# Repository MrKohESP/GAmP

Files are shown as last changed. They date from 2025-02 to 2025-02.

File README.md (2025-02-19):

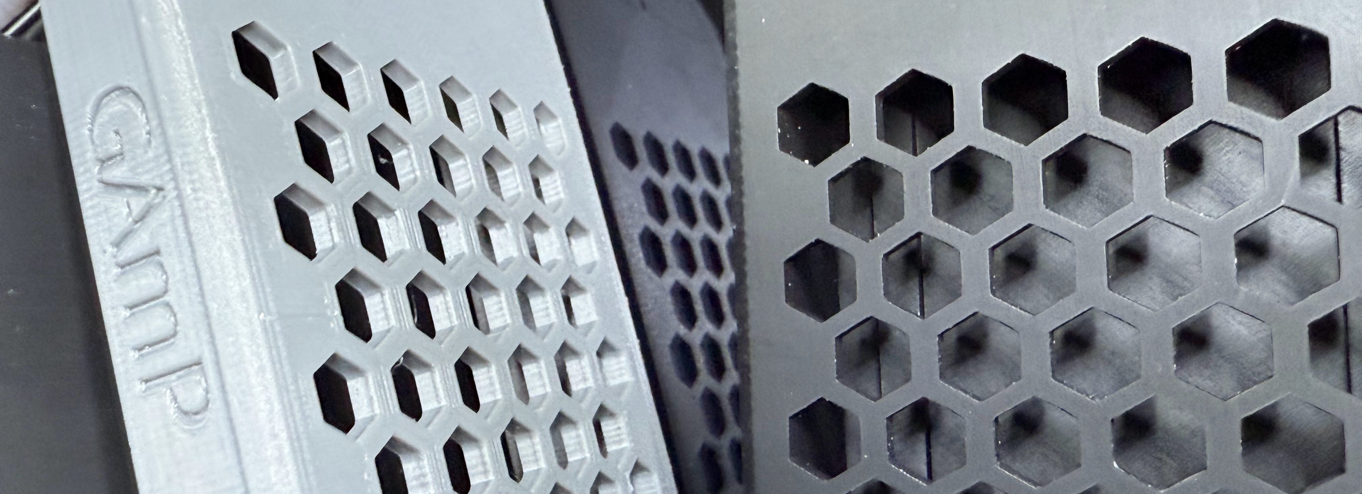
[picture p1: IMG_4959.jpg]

# GAmP
This circuit and subsequent project and headphone amplifier was designed and built for Mr. Koh's birthday.  It was built with web based tools only including [circuitlab.com](https:circuitlab.com), [EasyEDA](https://pro.easyeda.com/), and [onshape.com](https://onshape.com).

# Happy Birthday Mr. Koh 2025

This GAmP is a discret transister class A headphone amplifier capabable of driving headphones from 16 ohms to 600 ohms.  While only tested on 16 and 300 ohms the differences in performance for any impedences above 90 ohms were all similar.

# Schematic
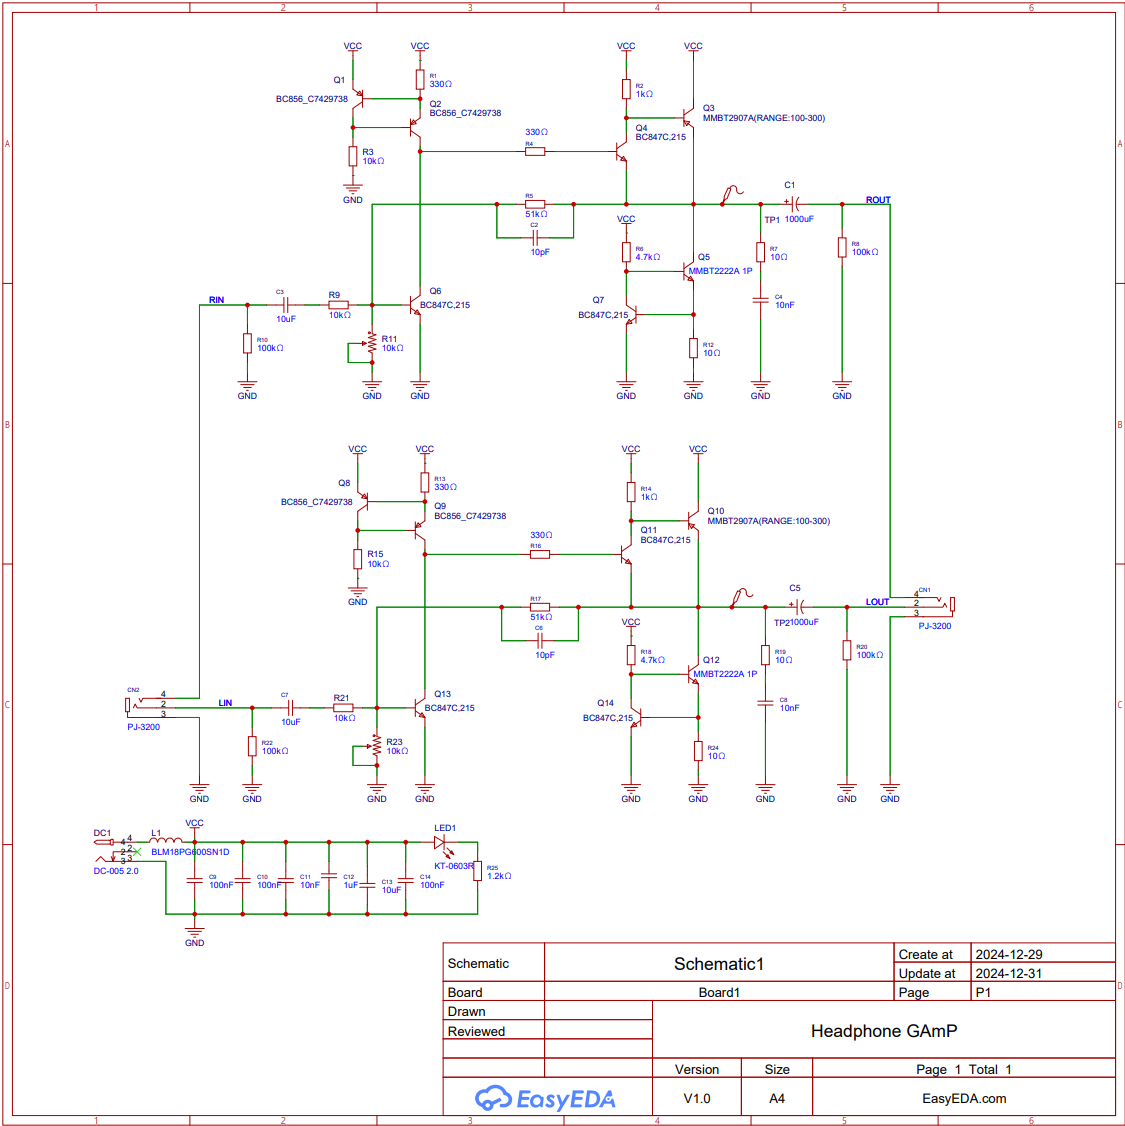
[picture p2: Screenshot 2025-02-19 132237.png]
Final Schematic


Full size pdf version: https://github.com/MrKohESP/GAmP/blob/main/SCH_Schematic1_2025-02-19.pdf

You can simulate this circuit using our [simulation link](https://www.circuitlab.com/circuit/v85n8m64j45p/headphone-amplifier/)

# BOM

The complete Bill of Materials is included below.

| ID | Name | Designator | Footprint | Quantity | Manufacturer Part | Manufacturer | Supplier | Supplier Part |
|----|---|---|---|---|---|---|---|---|
| 1  | BC856 | Q8,Q9,Q1,Q2 | SOT-23-3_L2.9-W1.3-P1.90-LS2.6-BR | 4 | BC856 | BLUE ROCKET | LCSC | C7429738 |
| 2  | BC847C,215 | Q11,Q14,Q13,Q4,Q7,Q6 | SOT-23-3_L2.9-W1.6-P1.90-LS2.8-BR | 6 | BC847C,215 | Nexperia | LCSC | C8664 |
| 3  | MMBT2907A(RANGE:100-300) | Q10,Q3 | SOT-23-3_L3.0-W1.7-P0.95-LS2.9-BR | 2 | MMBT2907A(RANGE:100-300) | CJ | LCSC | C43692 |
| 4  | 100nF | C9,C10,C14 | C0402 | 3 | CL05B104KB54PNC | SAMSUNG | LCSC | C307331 |
| 5  | 10pF | C6,C2 | C0603 | 2 | CL10C100JB8NNNC | SAMSUNG | LCSC | C1634 |
| 6  | 10k? | R23,R11 | RES-ADJ-TH_3P-L10.0-W10.0-P2.50-L | 2 | 3296W-1-103 | BOCHEN | LCSC | C118954 |
| 7  | DC-005 2.0 | DC1 | DC-IN-TH_DC-5520-1 | 1 | DC-005 2.0 | BOOMELE | LCSC | C16214 |
| 8  | 1000uF | C5,C1 | CAP-TH_BD10.0-P5.00-D1.0-FD | 2 | KM108M025G17RR0VH2FP0 | CX | LCSC | C10750 |
| 9  | 10nF | C8,C11,C4 | C0402 | 3 | CL05B103KB5NNNC | SAMSUNG | LCSC | C15195 |
| 10 | 1uF | C12 | C0603 | 1 | CL10A105KB8NNNC | SAMSUNG | LCSC | C15849 |
| 11 | 10uF | C7,C3 | C0603 | 2 | CL10A106MA8NRNC | SAMSUNG | LCSC | C96446 |
| 12 | 10uF | C13 | C0805 | 1 | CL21A106KAYNNNE | SAMSUNG | LCSC | C15850 |
| 13 | KT-0603R | LED1 | LED0603-RD | 1 | KT-0603R | KENTO | LCSC | C2286 |
| 14 | BLM18PG600SN1D | L1 | L0603 | 1 | BLM18PG600SN1D | muRata | LCSC | C85834 |
| 15 | 330? | R13,R16,R1,R4 | R0402 | 4 | 0402WGF3300TCE | UNI-ROYAL | LCSC | C25104 |
| 16 | 10k? | R15,R21,R3,R9 | R0402 | 4 | 0402WGF1002TCE | UNI-ROYAL | LCSC | C25744 |
| 17 | 1k? | R14,R2 | R0402 | 2 | 0402WGF1001TCE | UNI-ROYAL | LCSC | C11702 |
| 18 | 4.7k? | R18,R6 | R0402 | 2 | 0402WGF4701TCE | UNI-ROYAL | LCSC | C25900 |
| 19 | 51k? | R17,R5 | R0402 | 2 | 0402WGF5102TCE | UNI-ROYAL | LCSC | C25794 |
| 20 | 100k? | R22,R20,R10,R8 | R0402 | 4 | 0402WGF1003TCE | UNI-ROYAL | LCSC | C25741 |
| 21 | 10? | R19,R24,R7,R12 | R0603 | 4 | 0603WAF100JT5E | UNI-ROYAL | LCSC | C22859 |
| 22 | 1.2k? | R25 | R0603 | 1 | 0603WAF1201T5E | UNI-ROYAL | LCSC | C22765 |
| 23 | MMBT2222A 1P | Q12,Q5 | SOT-23-3_L2.9-W1.3-P1.90-LS2.4-BR | 2 | MMBT2222A 1P | CJ | LCSC | C8512 |
| 24 | PJ-3200 | CN2,CN1 | AUDIO-TH_PJ-3200 | 2 | PJ-3200 | XKB Connectivity | LCSC | C2689690 |
| 25 | Test-Point | TP1,TP2 | Test-Point-0.5mm | 2 | | | | |

# PCB

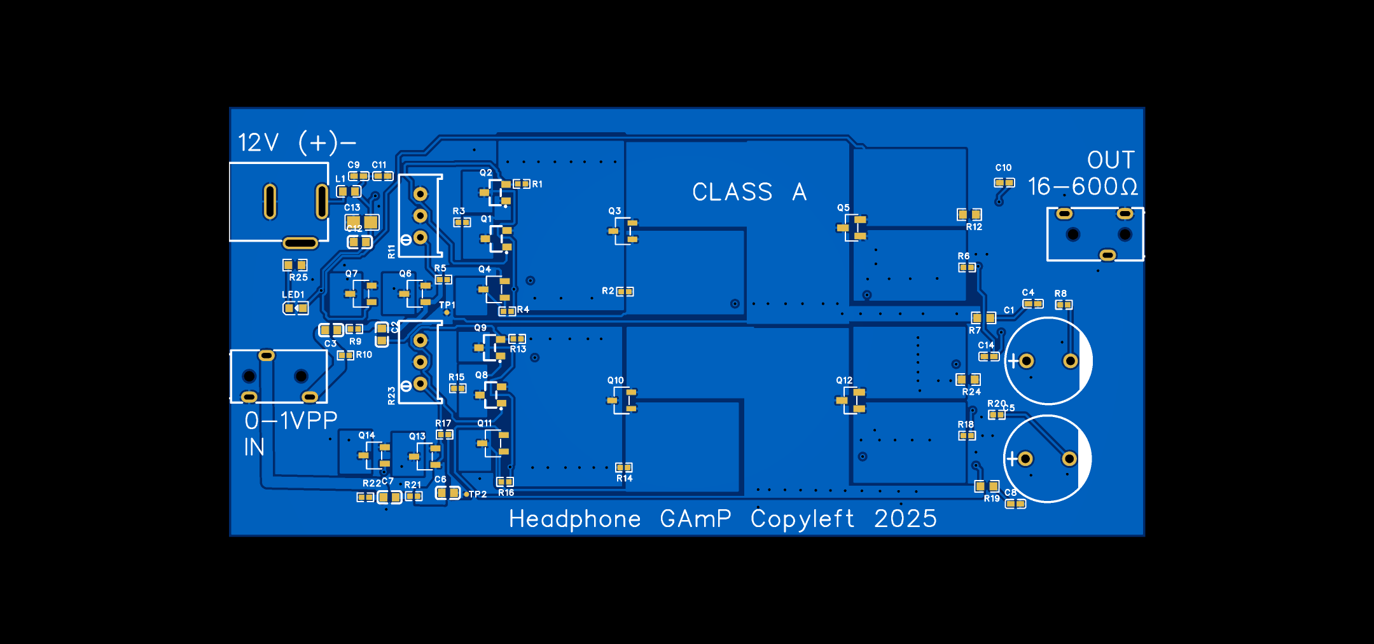
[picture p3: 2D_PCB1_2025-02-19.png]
Front Side


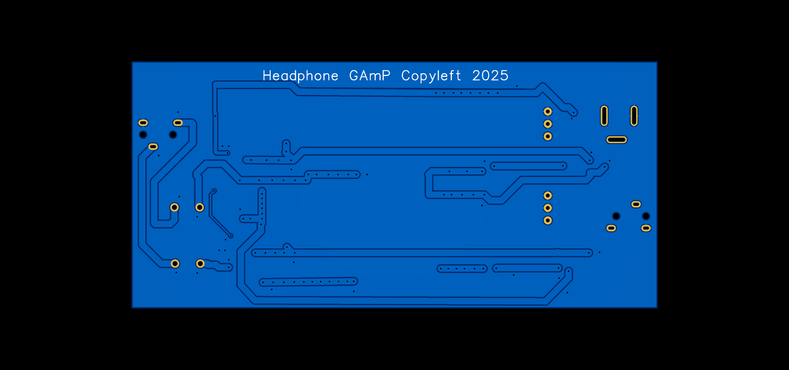
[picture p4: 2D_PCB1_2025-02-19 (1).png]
Back Side


# 3D Model of PCB

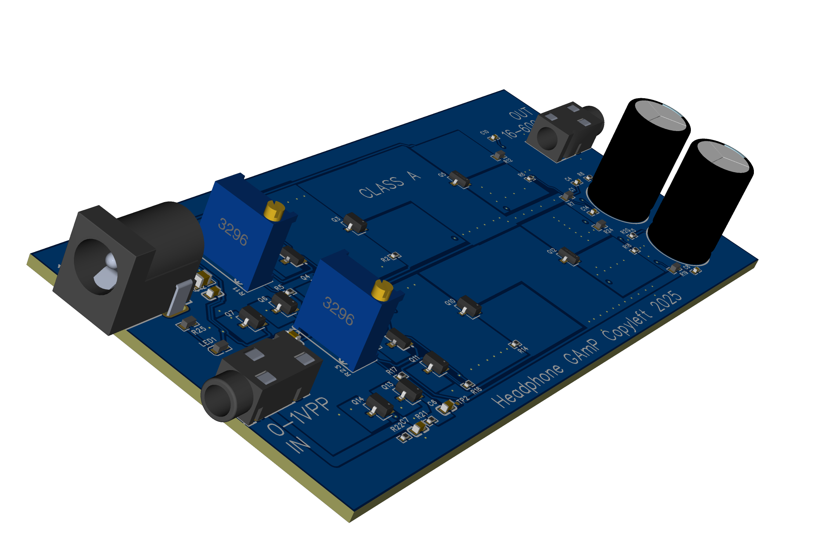
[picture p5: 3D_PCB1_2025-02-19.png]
3D Image


Full size step version: https://github.com/MrKohESP/GAmP/blob/6eb4d379a9d827a5ec4db1e81b124d0b5fc4782c/3D_PCB1_2025-02-19.step

# PCB Production

Production Timeline

# Enclosure

The enclosure is a custom designed SLA 3D printed snap-fit, vented, and split case.  Designed in OnShape an online 3D modeling site.  
 
The complete assembly and models here: https://cad.onshape.com/documents/f1fd810423af36052080a337/w/e044fea8778af83a679eb873/e/5cdc29b059e584418c251eba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

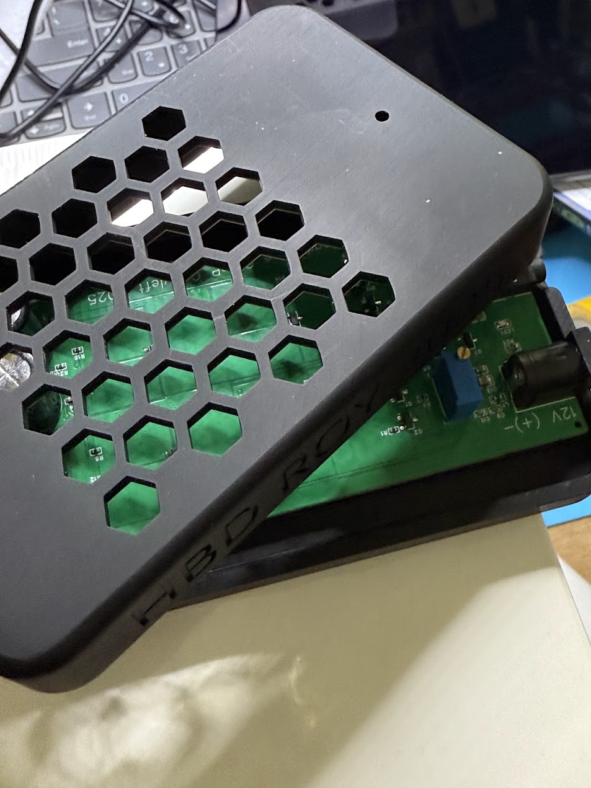
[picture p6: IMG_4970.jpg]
Enclosure


# 3D Models of the Enclosure

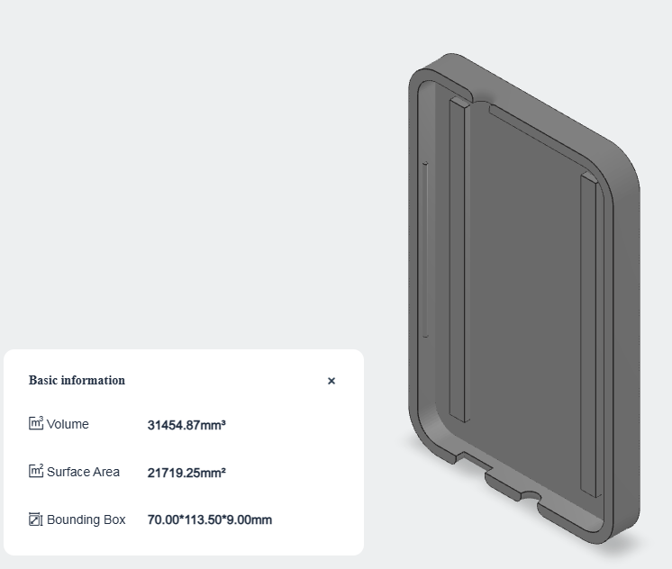
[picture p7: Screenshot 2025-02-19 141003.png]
Bottom


Full size stl file bottom: 
https://github.com/MrKohESP/GAmP/blob/6eb4d379a9d827a5ec4db1e81b124d0b5fc4782c/GAmP%2BvX%2BBottom.stl)

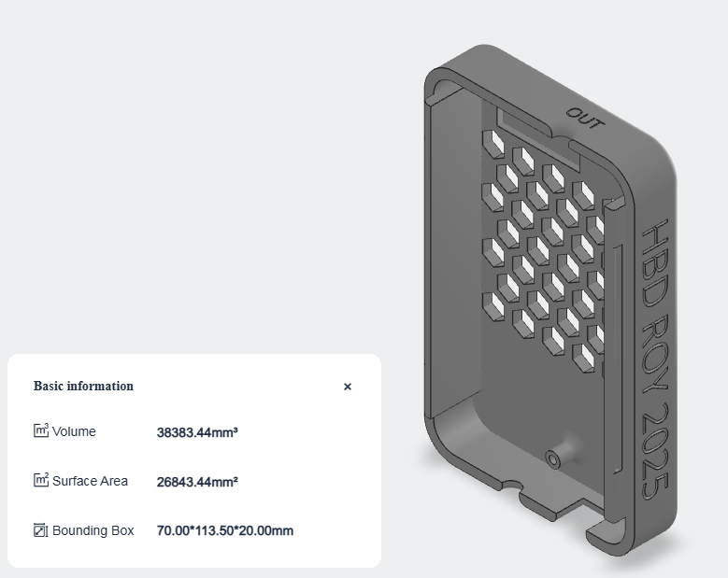
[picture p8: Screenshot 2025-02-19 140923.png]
Top


Full size stl file top:
https://github.com/MrKohESP/GAmP/blob/6eb4d379a9d827a5ec4db1e81b124d0b5fc4782c/GAmP%2BvX%2BTop.stl)

# Enclosure Production

Production Timeline

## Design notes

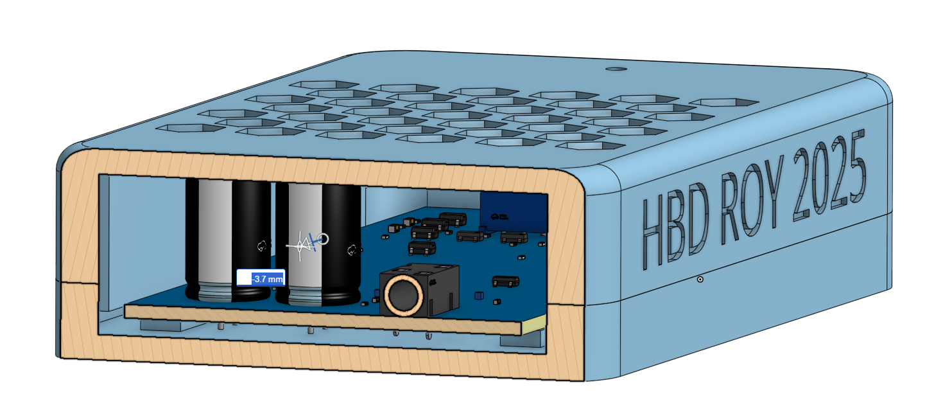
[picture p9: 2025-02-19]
Screenshot 2025-02-19 141844.png

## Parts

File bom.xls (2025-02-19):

Comment | Designator | Footprint | JLCPCB Part #
10uF | C13 | C0805 | C15850
DC-0052.0 | DC1 | DC-IN-TH_DC-5520-1 | C16214
51kΩ | R5,R17 | R0402 | C25794
10pF | C2,C6 | C0603 | C1634
1000uF | C1,C5 | CAP-TH_BD10.0-P5.00-D1.0-FD | C10750
10kΩ | R11,R23 | RES-ADJ-TH_3P-L10.0-W10.0-P2.50-L | C118954
330Ω | R1,R4,R13,R16 | R0402 | C25104
PJ-3200 | CN1,CN2 | AUDIO-TH_PJ-3200 | C2689690
BLM18PG600SN1D | L1 | L0603 | C85834
1kΩ | R2,R14 | R0402 | C11702
BC847C,215 | Q4,Q6,Q7,Q11,Q13,Q14 | SOT-23-3_L2.9-W1.6-P1.90-LS2.8-BR | C8664
10Ω | R7,R12,R19,R24 | R0603 | C22859
MMBT2222A1P | Q5,Q12 | SOT-23-3_L2.9-W1.3-P1.90-LS2.4-BR | C8512
10uF | C3,C7 | C0603 | C96446
1.2kΩ | R25 | R0603 | C22765
4.7kΩ | R6,R18 | R0402 | C25900
10kΩ | R3,R9,R15,R21 | R0402 | C25744
100kΩ | R8,R10,R20,R22 | R0402 | C25741
KT-0603R | LED1 | LED0603-RD | C2286
MMBT2907A(RANGE:100-300) | Q3,Q10 | SOT-23-3_L3.0-W1.7-P0.95-LS2.9-BR | C43692
10nF | C4,C8,C11 | C0402 | C15195
1uF | C12 | C0603 | C15849
100nF | C9,C10,C14 | C0402 | C307331
BC856 | Q1,Q2,Q8,Q9 | SOT-23-3_L2.9-W1.3-P1.90-LS2.6-BR | C7429738

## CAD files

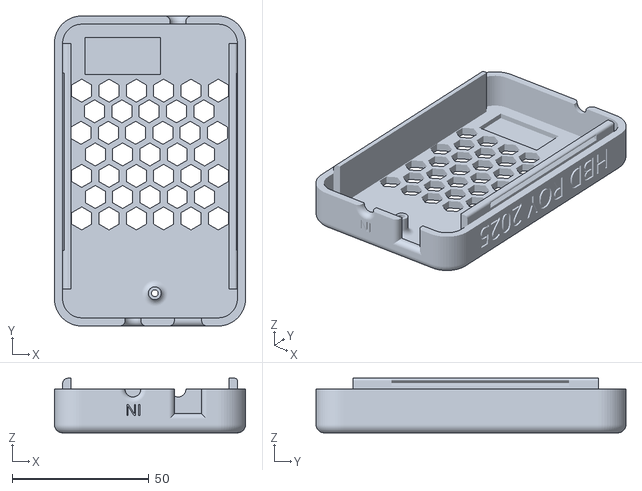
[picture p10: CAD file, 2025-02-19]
GAmP+vX+Top.stl
70.0 x 113.5 x 20.0

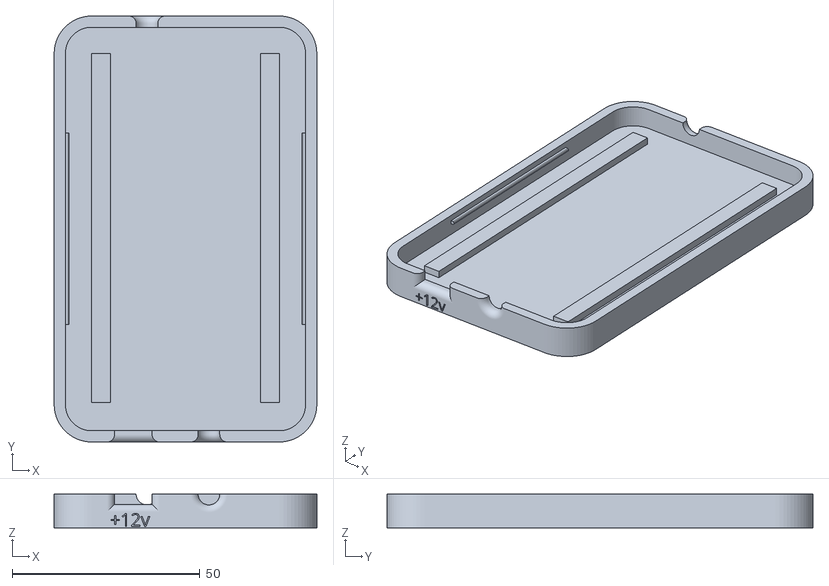
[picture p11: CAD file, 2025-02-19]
GAmP+vX+Bottom.stl
70.0 x 113.5 x 9.00

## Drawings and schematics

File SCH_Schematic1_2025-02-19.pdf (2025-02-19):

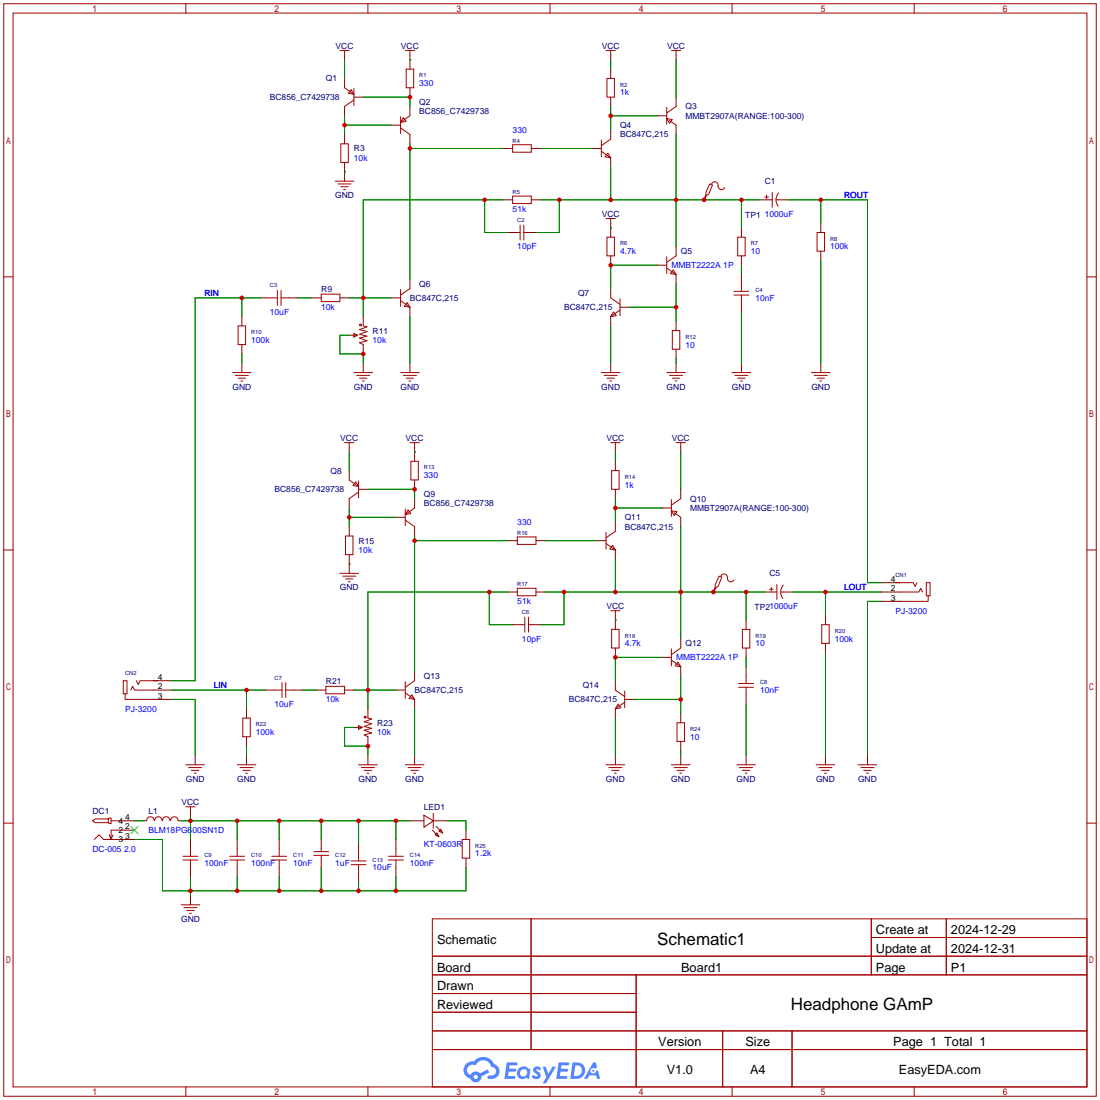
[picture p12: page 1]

Schematic | Schematic1 | Create at | 2024-12-29

Update at | 2024-12-31

Board | Board1 | Page | P1
Drawn | | Headphone GAmP
Reviewed

Version | Size | Page 1 Total 1
V1.0 | A4 | EasyEDA.com
